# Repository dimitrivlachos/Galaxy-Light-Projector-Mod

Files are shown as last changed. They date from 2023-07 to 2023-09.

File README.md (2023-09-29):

# Galaxy Light Projector Mod
Modification of a consumer night-light projector, converting it into a smart device with a custom PCB, powered by an ESP-32.

## Features
- Alexa integration
- Complex color patterns
- Improved brightness
- Better circuit protection

## Custom PCB

### KiCad Render (Rev. 1.1)
<table>
  <tr>
    <td>Front</td>
  </tr>
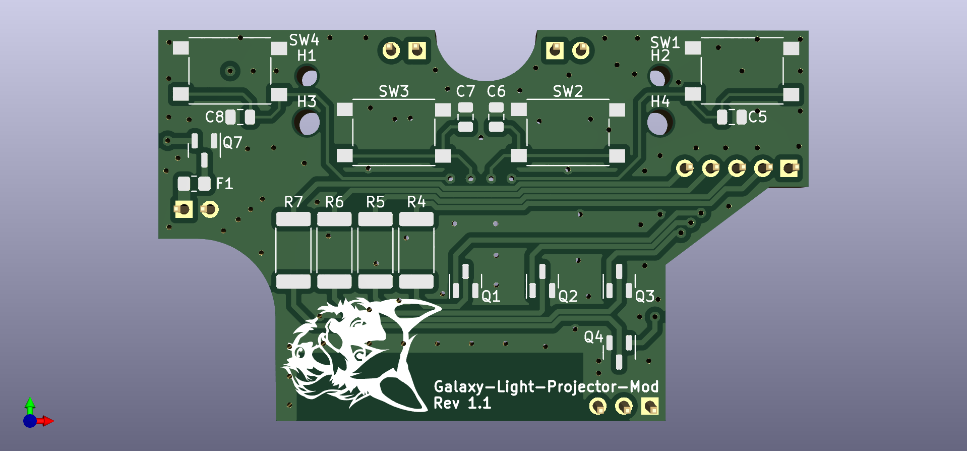
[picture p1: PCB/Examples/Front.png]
    <td></td>
  </tr>
  <tr>
    <td>Back</td>
  </tr>
  <tr>
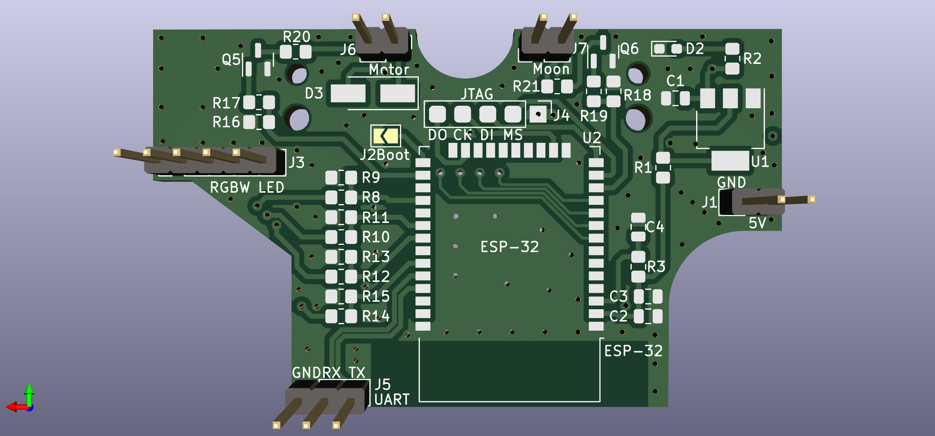
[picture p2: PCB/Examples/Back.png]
    <td></td>
 </table>

 ### Fabrication Render (Rev. 1.1)
  <table>
    <tr>
      <td>Front</td>
    </tr>
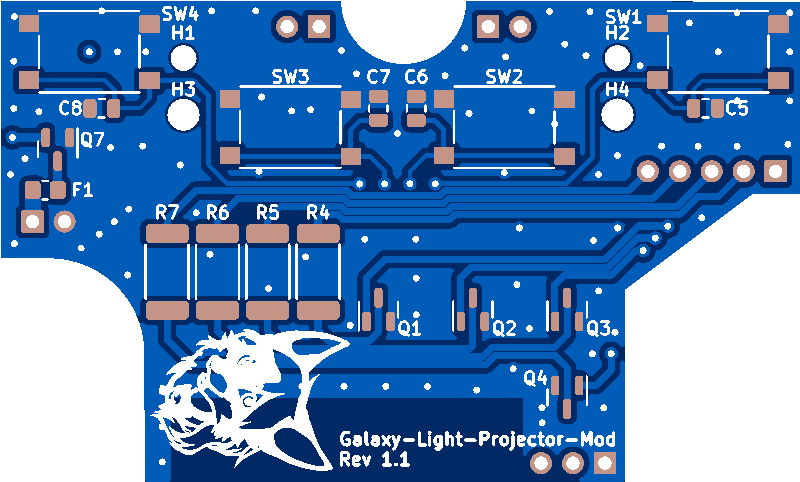
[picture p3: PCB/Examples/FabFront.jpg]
      <td></td>
    </tr>
    <tr>
      <td>Back</td>
    </tr>
    <tr>
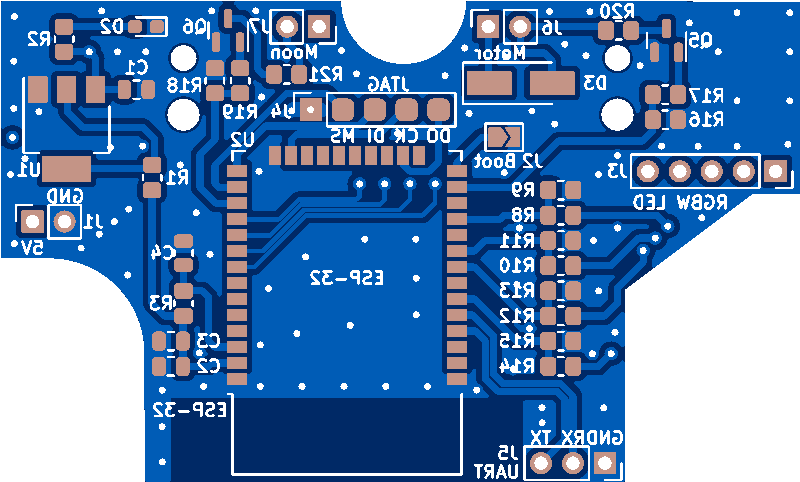
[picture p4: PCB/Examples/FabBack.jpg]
      <td></td>
    </table>

### Printed Circuit Board (Rev. 1.0)
<table>
  <tr>
    <td>Bare</td>
  </tr>
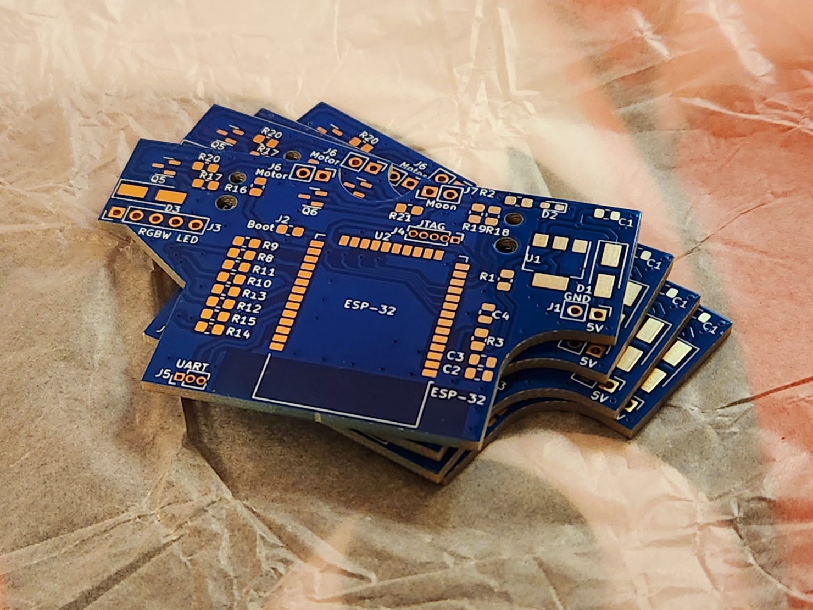
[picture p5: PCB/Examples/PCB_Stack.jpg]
    <td></td>
  <tr>
    <td>Assembled Front</td>
  </tr>
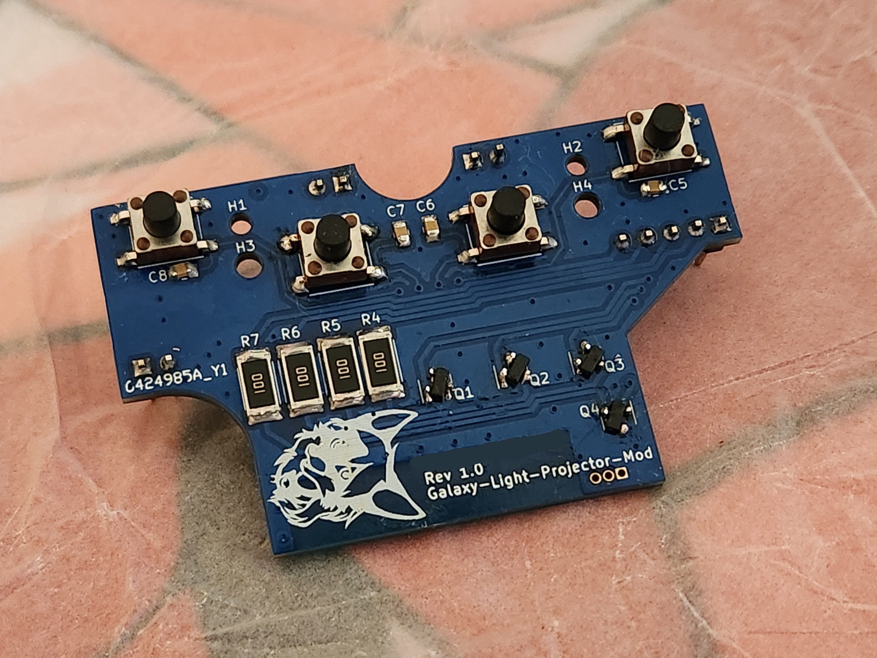
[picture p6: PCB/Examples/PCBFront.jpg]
    <td></td>
  </tr>
  <tr>
    <td>Assembled Back</td>
  </tr>
  <tr>
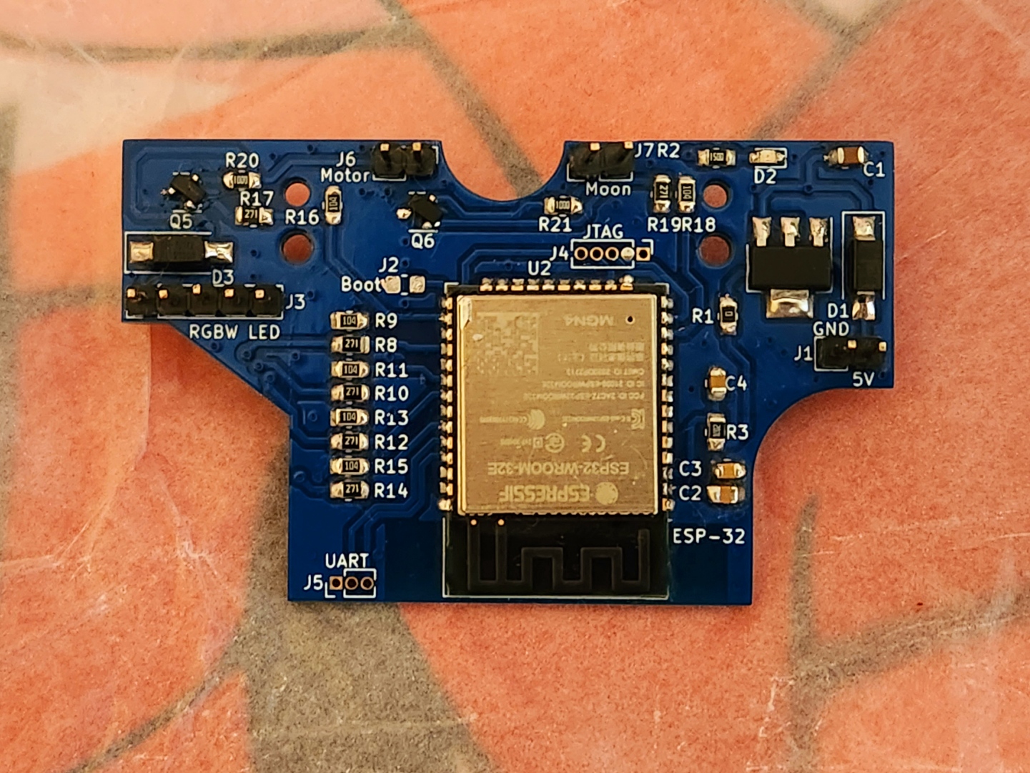
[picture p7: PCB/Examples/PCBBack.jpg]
    <td></td>
 </table>

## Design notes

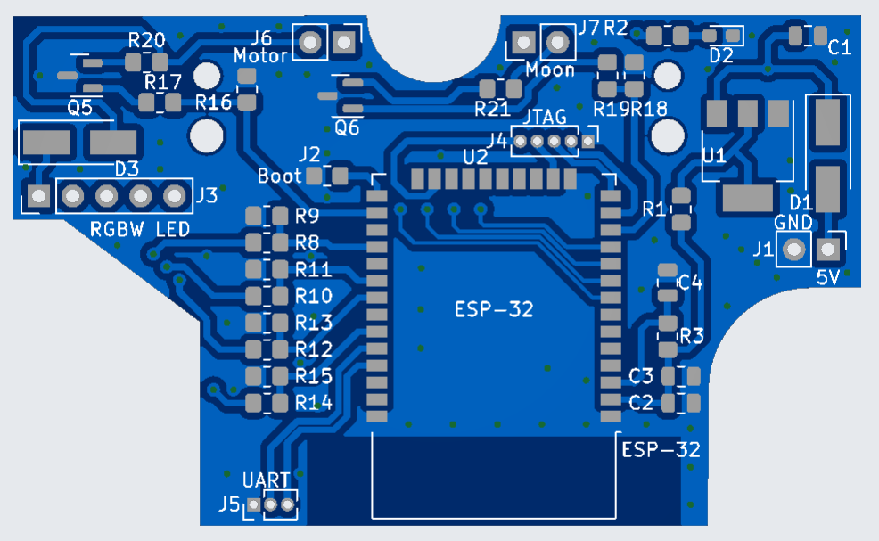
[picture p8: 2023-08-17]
PCB/Examples/FabBack.png

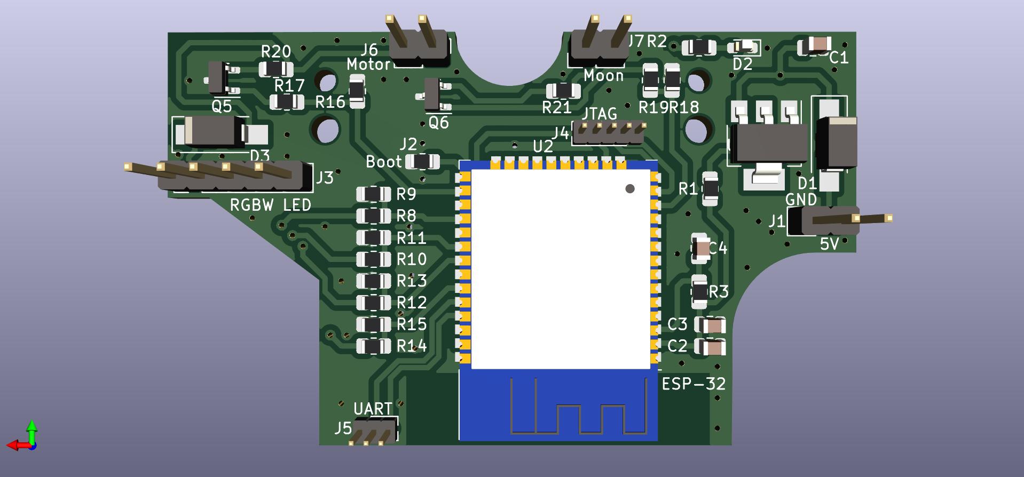
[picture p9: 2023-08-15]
PCB/Examples/Back.jpg

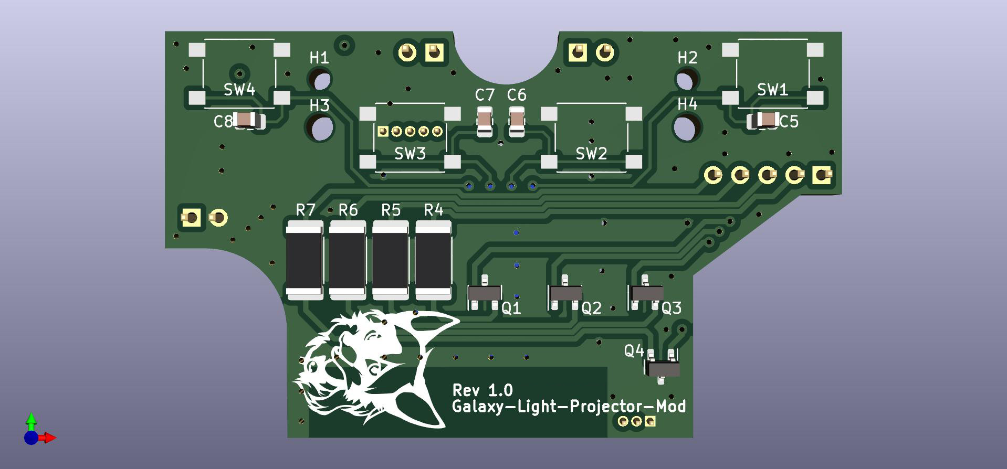
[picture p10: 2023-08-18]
PCB/Examples/Front.jpg

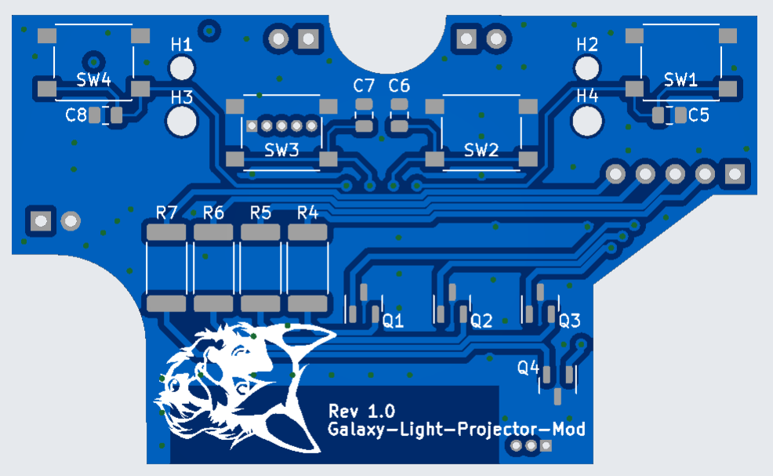
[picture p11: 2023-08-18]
PCB/Examples/FabFront.png

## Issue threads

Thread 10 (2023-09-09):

Switch footprint needs correction

dimitrivlachos, 2023-09-09:
Actual tactile switch footprint slightly different than described in datasheet and this needs correction on the board

Closed 2023-09-28.

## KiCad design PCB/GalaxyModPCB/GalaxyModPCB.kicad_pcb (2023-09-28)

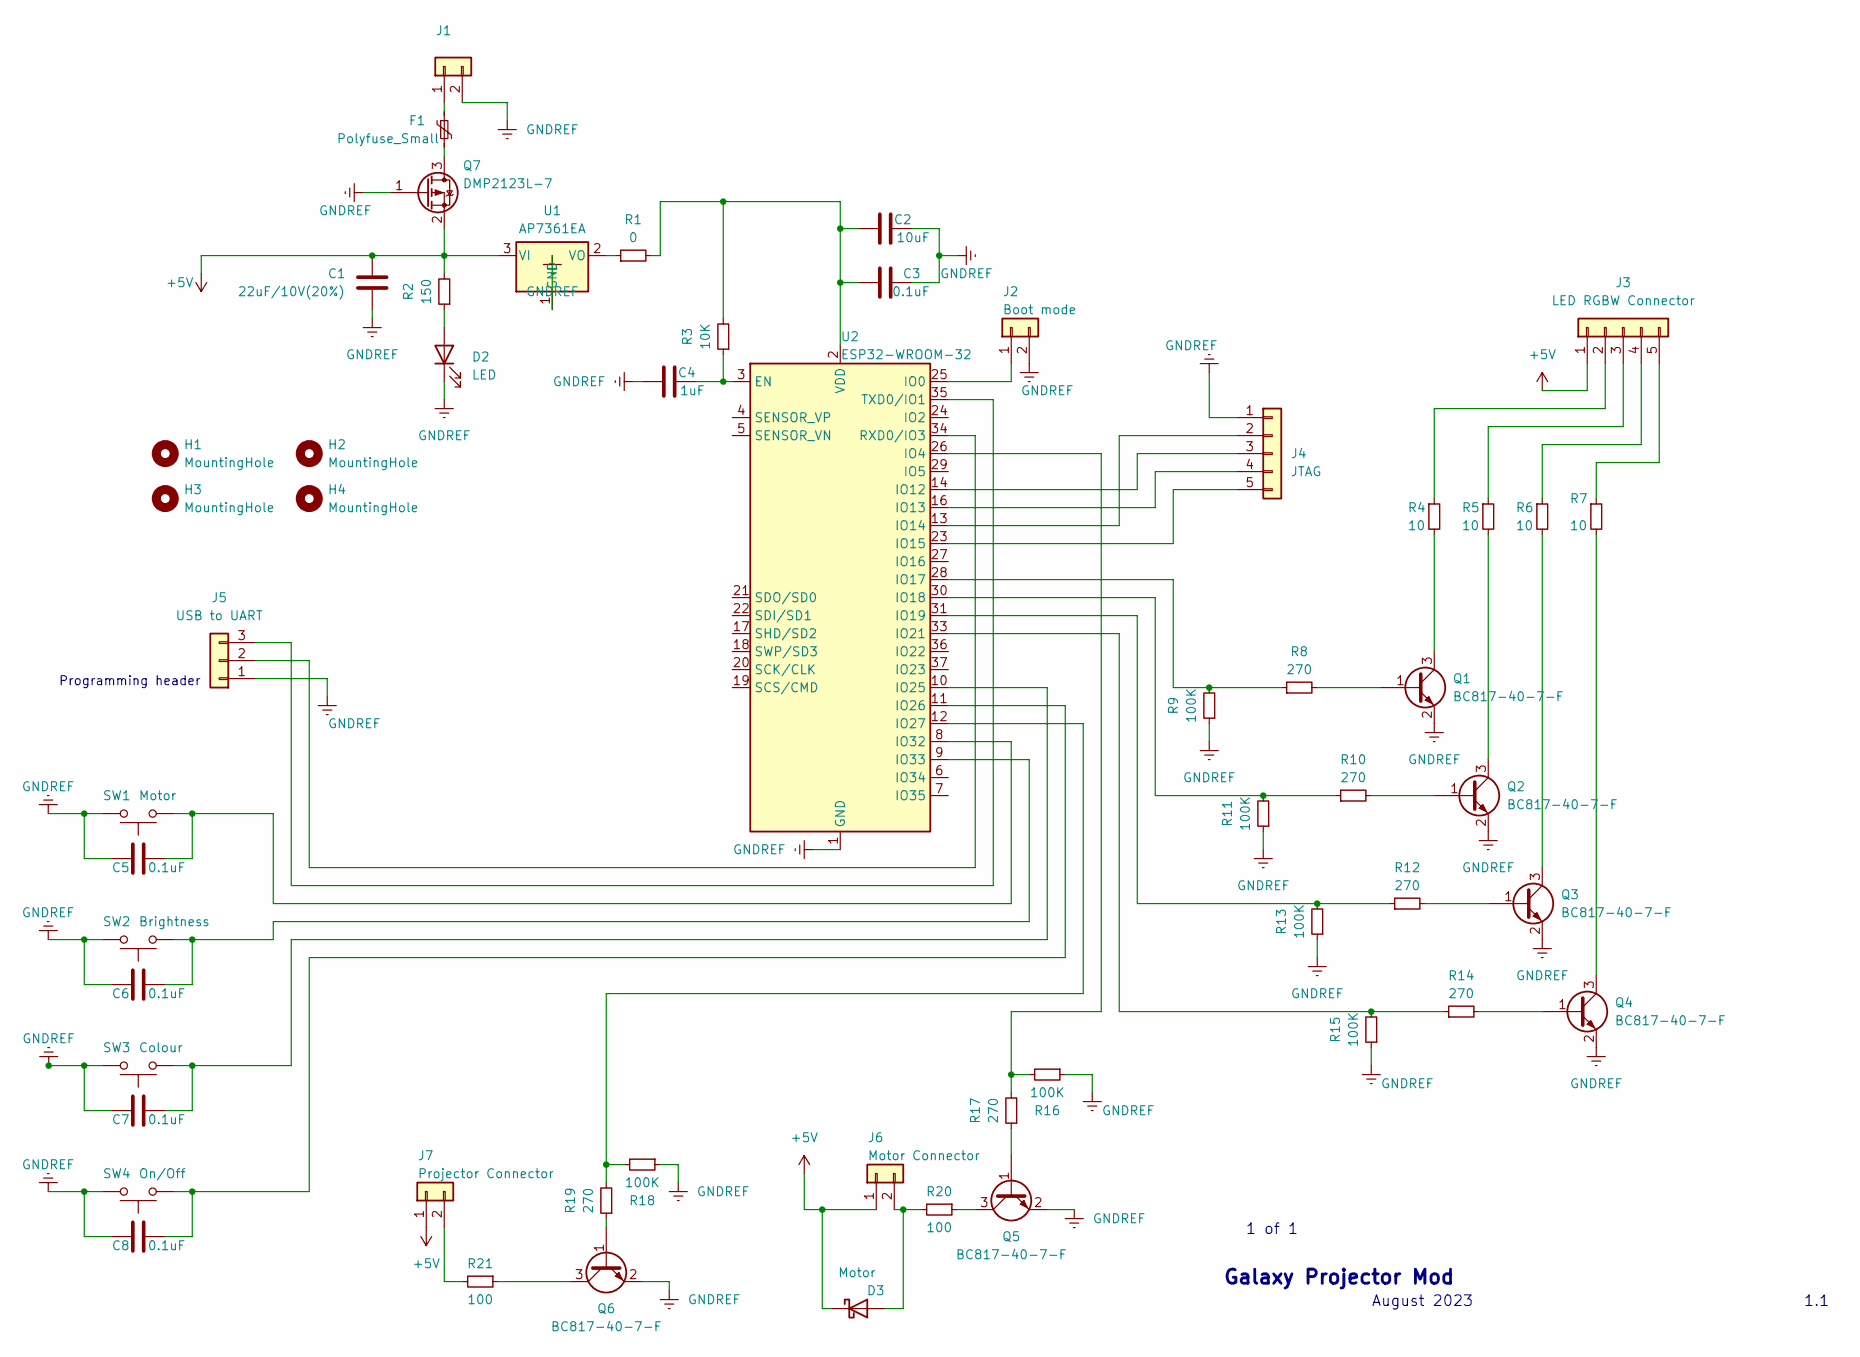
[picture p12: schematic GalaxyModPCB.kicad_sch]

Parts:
C1: 22uF/10V(20%); C_0805_2012Metric
C2: 10uF; C_0805_2012Metric
C3, C5, C6, C7, C8: 0.1uF; C_0805_2012Metric
C4: 1uF; C_0805_2012Metric
D2: LED; LED_0603_1608Metric_Pad1.05x0.95mm_HandSolder
D3: Motor; D_SMA_Handsoldering JLCPCB
F1: Polyfuse_Small; R_0805_2012Metric_Pad1.20x1.40mm_HandSolder
H1, H2: MountingHole; MountingHole_2mm Galaxy Small
H3, H4: MountingHole; 2.5mm Big Hole
J1: Power Header; PinHeader_1x02_P2.54mm_Vertical
J2: Boot mode; Triangle Jumper
J3: LED RGBW Connector; PinHeader_1x05_P2.54mm_Vertical
J4: JTAG; JTAG Connector
J5: USB to UART; UART Connector
J6: Motor Connector; PinHeader_1x02_P2.54mm_Vertical
J7: Projector Connector; PinHeader_1x02_P2.54mm_Vertical
Q1, Q2, Q3, Q4, Q5, Q6: BC817-40-7-F; SOT-23
Q7: DMP2123L-7; SOT-23
R1: 0; R_0805_2012Metric_Pad1.20x1.40mm_HandSolder
R2: 150; R_0805_2012Metric_Pad1.20x1.40mm_HandSolder
R3: 10K; R_0805_2012Metric_Pad1.20x1.40mm_HandSolder
R4, R5, R6, R7: 10; R_2512_6332Metric_Pad1.40x3.35mm_HandSolder
R8, R10, R12, R14, R17, R19: 270; R_0805_2012Metric_Pad1.20x1.40mm_HandSolder
R9, R11, R13, R15, R16, R18: 100K; R_0805_2012Metric_Pad1.20x1.40mm_HandSolder
R20, R21: 100; R_0805_2012Metric_Pad1.20x1.40mm_HandSolder
SW1: Motor; Galaxy Switch
SW2: Brightness; Galaxy Switch
SW3: Colour; Galaxy Switch
SW4: On/Off; Galaxy Switch
U1: AP7361EA; SOT-223-3_TabPin2
U2: ESP32-WROOM-32; ESP32-WROOM-32 No Thermal

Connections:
+5V: C1.1, D3.1 (K), J3.1, J6.1, J7.1, Q7.2 (S), R2.2, U1.3 (VI)
GNDREF: C1.2, C2.2, C3.2, C4.1, C5.2, C6.2, C7.2, C8.2, D2.1 (K), J1.2, J2.2, J4.1, J5.1, Q1.2 (E), Q2.2 (E), Q3.2 (E), Q4.2 (E), Q5.2 (E), Q6.2 (E), Q7.1 (G), R9.1, R11.1, R13.1, R15.1, R16.1, R18.1, SW1.2, SW2.2, SW3.2, SW4.2, U1.1 (GND), U2.1 (GND), U2.15 (GND), U2.38 (GND), U2.39 (GND)
unnamed: D2.2 (A), R2.1
unnamed: D3.2 (A), J6.2, R20.2
unnamed: F1.1, J1.1
unnamed: J2.1, U2.25 (IO0)
unnamed: J3.2, R4.1
unnamed: J3.3, R5.1
unnamed: J3.4, R6.1
unnamed: J3.5, R7.1
unnamed: J4.2, U2.13 (IO14)
unnamed: J4.3, U2.14 (IO12)
unnamed: J4.4, U2.16 (IO13)
unnamed: J4.5, U2.23 (IO15)
unnamed: J5.2, U2.34 (RXD0/IO3)
unnamed: J5.3, U2.35 (TXD0/IO1)
unnamed: J7.2, R21.2
unnamed: Q1.1 (B), R8.2
unnamed: Q1.3 (C), R4.2
unnamed: Q2.1 (B), R10.2
unnamed: Q2.3 (C), R5.2
unnamed: Q3.1 (B), R12.2
unnamed: Q3.3 (C), R6.2
unnamed: Q4.1 (B), R14.2
unnamed: Q4.3 (C), R7.2
unnamed: Q5.1 (B), R17.1
unnamed: Q5.3 (C), R20.1
unnamed: Q6.1 (B), R19.1
unnamed: Q6.3 (C), R21.1
unnamed: F1.2, Q7.3 (D)
unnamed: R1.1, U1.2 (VO)
unnamed: C4.2, R3.1, U2.3 (EN)
unnamed: R16.2, R17.2, U2.26 (IO4)
unnamed: R8.1, R9.2, U2.28 (IO17)
unnamed: R10.1, R11.2, U2.30 (IO18)
unnamed: R12.1, R13.2, U2.31 (IO19)
unnamed: R14.1, R15.2, U2.33 (IO21)
unnamed: C7.1, SW3.1, U2.10 (IO25)
unnamed: C8.1, SW4.1, U2.11 (IO26)
unnamed: R18.2, R19.2, U2.12 (IO27)
unnamed: C5.1, SW1.1, U2.8 (IO32)
unnamed: C6.1, SW2.1, U2.9 (IO33)
unnamed: C2.1, C3.1, R1.2, R3.2, U2.2 (VDD)

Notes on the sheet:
1.1
Galaxy Projector Mod
1 of 1
August 2023
Programming header

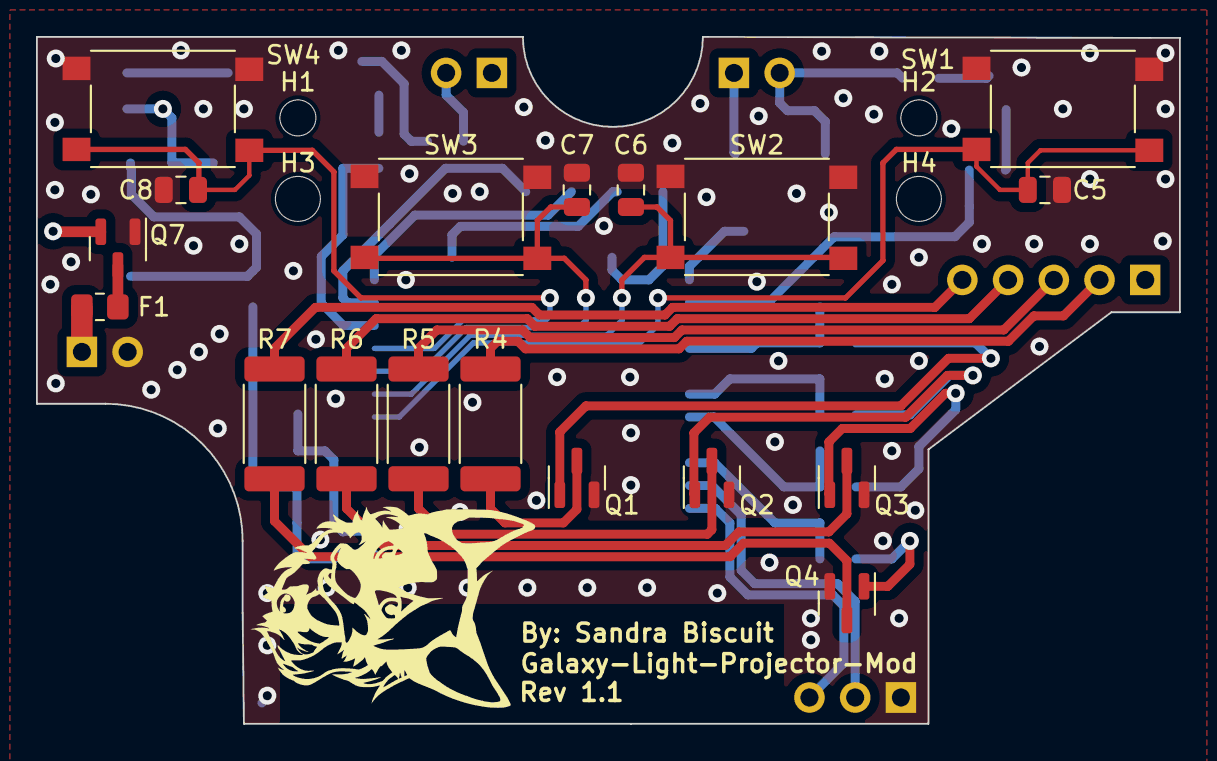
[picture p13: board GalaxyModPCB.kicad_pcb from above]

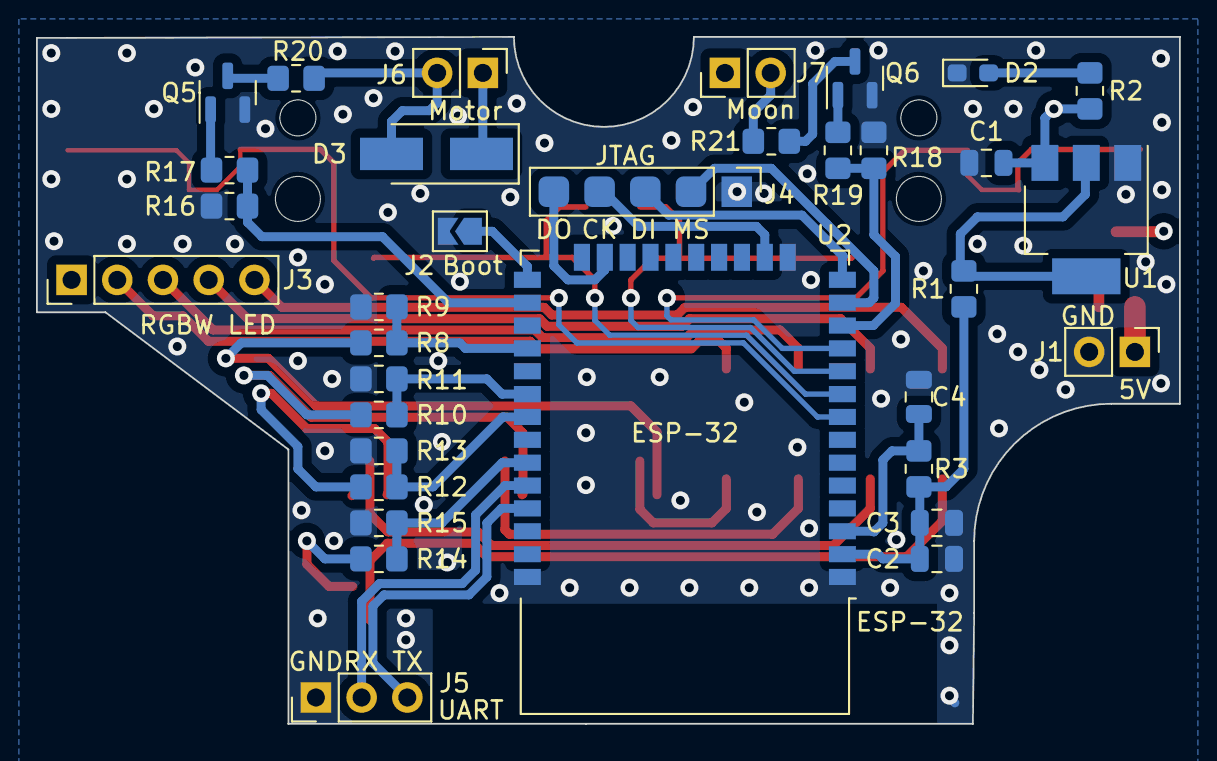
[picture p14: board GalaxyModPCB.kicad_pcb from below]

Board: 4 copper layers, 63.5 x 38.2 mm, 56 parts (34 on the bottom side), 43 nets.

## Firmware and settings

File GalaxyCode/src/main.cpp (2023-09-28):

#include <Arduino.h>
#include <WiFi.h>
#include <AsyncTCP.h>
#include <ESPAsyncWebServer.h>
#include <AsyncElegantOTA.h>
#include <Arduino_Json.h>

// Define and initialize the AsyncWebServer instance
AsyncWebServer server(80);
// Define and initialize the AsyncWebSocket instance
AsyncWebSocket ws("/ws");

// Task handles for the two core loops
TaskHandle_t TaskLoopCore0;
TaskHandle_t TaskLoopCore1;

// Switch state variables
bool motorSwitchState = false;
bool brightnessSwitchState = false;
bool colourSwitchState = false;
bool stateSwitchState = false;

// Brightness level variable
float brightness = 0.0;

// Maximum number of WiFi connection attempts
#define MAX_WIFI_ATTEMPTS 10
// Delay between WiFi connection attempts (in milliseconds)
#define WIFI_RETRY_DELAY 500
// Flag indicating WiFi connection status
bool wifiConnected = false;

#pragma region Function Declarations
// Core task function declarations
void LoopOutputHandle(void *pvParameters);
void LoopStateHandle(void *pvParameters);

// Function to connect to WiFi
void connectToWiFi();

// State handling function declarations
void setRGBWLed(int red, int green, int blue, int white);
void handlePowerState();
void handleRGBWState();
void handleMotorState();
void handleBrightnessState();

// Switch handling function declarations
void checkSwitch(int switchPin, bool &switchState, void (*callback)());
void handleStateSwitch();
void handleMotorSwitch();
void handleBrightnessSwitch();
void handleColourSwitch();

// Template function for incrementing enums
template <typename T>
T incrementEnum(T &enumValue, T lastEnumValue);

// Template function for handling switch state changes
template <typename EnumType>
void handleSwitch(EnumType &enumState, EnumType lastEnumValue, const char *switchName);

// WebSocket handling function declarations
void onEvent(AsyncWebSocket *server, AsyncWebSocketClient *client, AwsEventType type,
             void *arg, uint8_t *data, size_t len);
void handleWebSocketMessage(void *arg, uint8_t *payload, size_t length);
void initWebSocket();
String generateJsonForStates();
void updateClients();
#pragma endregion

#pragma region Wifi Settings
// WiFi configuration settings
const char *SSID = "ssid";
const char *PASSWORD = "pass";
const char *HOSTNAME = "GalaxyProjector-Dev";
const IPAddress STATIC_IP(192, 168, 0, 50);
const IPAddress GATEWAY(192, 168, 0, 1);
const IPAddress SUBNET(255, 255, 255, 0);
#pragma endregion

#pragma region Pin Definitions
// Pin definitions for various components
#define RED_LED 19            // Green wire
#define WHITE_LED 18          // Blue wire
#define GREEN_LED 17          // White wire
#define BLUE_LED 21           // Red wire
#define PROJECTOR_LED 27      // Moon projector
#define MOTOR_BJT 4           // Motor control
#define MOTOR_SWITCH 26       // Motor switch
#define BRIGHTNESS_SWITCH 25  // Brightness switch
#define COLOUR_SWITCH 33      // Colour switch
#define STATE_SWITCH 32       // State switch
#pragma endregion

#pragma region State Definitions
// Enumerations for various states
enum PowerStateEnum {
  PowerOff,
  On,
  Project,
  PowerLast
};
PowerStateEnum pStates = PowerOff;

enum RGBWStateEnum {
  Blue,
  Red,
  Green,
  White,
  BlueRed,
  BlueGreen,
  RedGreen,
  RedWhite,
  GreenWhite,
  RedGreenBlue,
  BlueGreenWhite,
  BlueRedGreenWhite,
  Cycle,
  LedLast
};
RGBWStateEnum rgbwStates = Blue;

enum MotorStateEnum {
  MotorOff,
  Fast,
  Slow,
  MotorLast
};
MotorStateEnum mStates = MotorOff;

enum BrightnessStateEnum {
  ExtraLow,
  Low,
  Medium,
  High,
  BrightnessLast
};
BrightnessStateEnum bStates = ExtraLow;
#pragma endregion

#pragma region HTML
const char index_html[] PROGMEM = R"rawliteral(
<!DOCTYPE HTML>
<html>
<head>
  <title>Galaxy Projector</title>
  <meta charset="UTF-8" name="viewport" content="width=device-width, initial-scale=1">
  <link rel="icon" href="data:,">
  <style>
    html {
      font-family: 'Arial', sans-serif;
      text-align: center;
      background-color: #111111;
      color: #ffffff;
    }
    h1 {
      font-size: 2rem;
      margin: 1rem;
    }
    h2 {
      font-size: 1.8rem;
      font-weight: bold;
      color: #00bfff;
    }
    .topnav {
      overflow: hidden;
      background-color: #111111;
      padding: 1rem;
    }
    body {
      margin: 0;
    }
    .content {
      padding: 2rem;
      max-width: 800px;
      margin: 0 auto;
    }
    .card {
      background-color: #1a1a1a;
      box-shadow: 0 0 10px rgba(255, 255, 255, 0.2);
      padding: 1rem;
      border-radius: 10px;
      text-align: center;
    }
    .button {
      padding: 15px 50px;
      font-size: 24px;
      text-align: center;
      outline: none;
      color: #fff;
      background-color: #00bfff;
      border: none;
      border-radius: 5px;
      cursor: pointer;
    }
    .button:active {
      background-color: #0099cc;
      box-shadow: 2px 2px 5px rgba(0, 0, 0, 0.3);
      transform: translateY(2px);
    }
    .state {
      font-size: 1.2rem;
      color: #8c8c8c;
    }
    .grid-container {
      display: grid;
      grid-template-columns: repeat(auto-fit, minmax(250px, 1fr));
      gap: 20px;
      margin-top: 1rem;
    }
  </style>
</head>
<body>
  <div class="topnav">
    <h1>🌠 Galaxy Projector 🌌</h1>
  </div>
  <div class="content">
    <div class="grid-container">
      <div class="card">
        <h2>Power</h2>
        <p><button id="Power" class="button">⚡️</button></p>
        <p class="state" id="PowerState">State: </p>
      </div>
      <div class="card">
        <h2>Brightness</h2>
        <p><button id="Brightness" class="button">☀️</button></p>
        <p class="state" id="BrightnessState">State: </p>
      </div>
      <div class="card">
        <h2>Colour</h2>
        <p><button id="Colour" class="button">🌈</button></p>
        <p class="state" id="ColourState">State: </p>
      </div>
      <div class="card">
        <h2>Spin</h2>
        <p><button id="Motor" class="button">💫</button></p>
        <p class="state" id="MotorState">State: </p>
      </div>
      <!-- Add more cards here -->
    </div>
  </div>
    <script>
      var gateway = `ws://${window.location.hostname}/ws`;
      var websocket;
      var statesDict = {
        "Power": ['🌑', '🌓', '🌕'],
        "Brightness": ['🌒', '🌓', '🌔', '🌕'],
        "Colour": ['🔵', '🔴', '🟢', '⚪️', '🔵🔴', '🔵🟢', '🔴🟢', '🔴⚪️', '🟢⚪️', '🔴🟢🔵', '🔵🟢⚪️', '🔵🔴🟢⚪️', '🔄'],
        "Motor": ['🛑', '🐇', '🐢']
      };
      window.addEventListener('load', onLoad);
  
      function initWebSocket() {
        console.log('Trying to open a WebSocket connection...');
        websocket = new WebSocket(gateway);
        websocket.onopen    = onOpen;
        websocket.onclose   = onClose;
        websocket.onmessage = onMessage;
      }
  
      function onOpen(event) {
        console.log('Connection opened');
        // Update the state of the buttons with the data received from the server
        sendMessage('getStates');
      }
  
      function onClose(event) {
        console.log('Connection closed');
        setTimeout(initWebSocket, 2000);
      }
  
      function onMessage(event) {
        console.log(`Received a message from server: ${event.data}`);
        try {
          var jsonData = JSON.parse(event.data);
          updateStates(jsonData);
        } catch (error) {
          console.error('Error parsing JSON:', error);
        }
      }
  
      function updateStates(data) {
        for (var key in data) {
          var stateElement = document.getElementById(key + 'State');
          if (stateElement) {
            stateElement.textContent = 'State: ' + statesDict[key][data[key]];
          }
        }
      }
  
      function onLoad(event) {
        initWebSocket();
        initButtons();
      }
  
      function initButtons() {
        // Initialize the buttons with their respective ids and listeners
        addButtonListener("Power");
        addButtonListener("Brightness");
        addButtonListener("Colour");
        addButtonListener("Motor");
      }
  
      function addButtonListener(buttonId) {
        var button = document.getElementById(buttonId);
        button.addEventListener('click', function() {
          sendMessage(buttonId);
        });
        button.buttonId = buttonId; // Store the button's id as a property for later use
      }
  
      function sendMessage(buttonId) {
        websocket.send(buttonId); // Send the button's id as a message to the ESP
      }
    </script>
</body>
</html>
)rawliteral";
#pragma endregion

void setup() {
  Serial.begin(115200);
  Serial.println("Booting");

  #pragma region Pin Initialisation
  pinMode(RED_LED, OUTPUT);
  pinMode(WHITE_LED, OUTPUT);
  pinMode(GREEN_LED, OUTPUT);
  pinMode(BLUE_LED, OUTPUT);
  pinMode(PROJECTOR_LED, OUTPUT);
  pinMode(MOTOR_BJT, OUTPUT);
  
  // Switches are active low so use INPUT_PULLUP
  pinMode(MOTOR_SWITCH, INPUT_PULLUP);
  pinMode(BRIGHTNESS_SWITCH, INPUT_PULLUP);
  pinMode(COLOUR_SWITCH, INPUT_PULLUP);
  pinMode(STATE_SWITCH, INPUT_PULLUP);
  #pragma endregion

  connectToWiFi();

  if(wifiConnected) {
    // Initialise WebSocket
    Serial.println("Initialising WebSocket");
    initWebSocket();
    Serial.println("WebSocket initialised");

    // Initialise OTA
    Serial.println("Initialising OTA");
    server.on("/", HTTP_GET, [](AsyncWebServerRequest *request) {
      request->send_P(200, "text/html", index_html);
    });
    AsyncElegantOTA.begin(&server);    // Start AsyncElegantOTA
    server.begin();
    Serial.println("HTTP server started");
    Serial.println("OTA initialised");
  }
  else {
    Serial.println("WiFi not connected, OTA not initialised. WebSocket not initialised. Continuing offline...");
  }

  Serial.println("Initialising Tasks");
  
  Serial.print("Initialising TaskLoopCore1... ");
  xTaskCreatePinnedToCore(
    LoopOutputHandle,     /* Task function. */
    "TaskLoopCore1",      /* name of task. */
    10000,                /* Stack size of task */
    NULL,                 /* parameter of the task */
    1,                    /* priority of the task */
    &TaskLoopCore0,       /* Task handle to keep track of created task */
    1);                   /* pin task to core 1 */          
  delay(500); 

  Serial.print("Initialising TaskLoopCore0... ");
  xTaskCreatePinnedToCore(
    LoopStateHandle,      /* Task function. */
    "TaskLoopCore0",      /* name of task. */
    10000,                /* Stack size of task */
    NULL,                 /* parameter of the task */
    1,                    /* priority of the task */
    &TaskLoopCore1,       /* Task handle to keep track of created task */
    0);                   /* pin task to core 0 */
  delay(500); 

  Serial.println("Tasks initialised");
  Serial.println("Setup complete!");
}

/**
 * Connects the device to a WiFi network using the provided SSID and password.
 * 
 * This function configures the WiFi mode, begins the connection process, sets the hostname,
 * and configures the IP address (if STATIC_IP is defined). It then attempts to connect
 * to the WiFi network, displaying connection progress. If the connection is successful,
 * the function updates the wifiConnected variable to true and prints the device's IP address.
 * If the connection fails, the function prints an error message, disconnects from WiFi,
 * and sets wifiConnected to false, allowing the device to continue offline.
 */
void connectToWiFi() {
  Serial.println("Connecting to WiFi...");
  
  // Set WiFi mode and begin connection
  WiFi.mode(WIFI_STA);
  WiFi.begin(SSID, PASSWORD);
  WiFi.setHostname(HOSTNAME);
  WiFi.config(STATIC_IP, GATEWAY, SUBNET);

  // Attempt to connect to WiFi
  int attemptCount = 0;
  while (WiFi.status() != WL_CONNECTED && attemptCount < MAX_WIFI_ATTEMPTS) {
    delay(WIFI_RETRY_DELAY);
    Serial.print(".");
    attemptCount++;
  }

  if (WiFi.status() == WL_CONNECTED) {
    Serial.println("\nConnected to WiFi");
    Serial.print("IP address: ");
    Serial.println(WiFi.localIP());
    wifiConnected = true; // Update wifiConnected status
  } else {
    Serial.println("\nFailed to connect to WiFi");
    WiFi.disconnect();    // Disconnect from WiFi
    wifiConnected = false; // Update wifiConnected status
    // Continue offline
    return;
  }
}

void loop() {
  ws.cleanupClients(); // Cleanup disconnected clients
}

#pragma region Output Handlers
/**
 * Task function to handle the output loop on a specific core.
 *
 * This task function is responsible for managing the output-related operations
 * of the device. It continuously handles the power state, brightness state,
 * RGBW state, and motor state according to their respective conditions.
 *
 * @param pvParameters A pointer to the parameters passed to the task (not used in this case).
 */
void LoopOutputHandle(void *pvParameters) {
  // Print the core ID for debugging purposes
  Serial.print("TaskLoopCore1 running on core ");
  Serial.println(xPortGetCoreID());

  // Enter the main loop
  for (;;) {
    // Handle power state regardless of other states
    handlePowerState();

    // Skip handling other states if the device is powered off
    if (pStates == PowerStateEnum::PowerOff) {
      continue;
    }

    // Handle brightness state
    handleBrightnessState();

    // Handle RGBW state
    handleRGBWState();

    // Handle motor state
    handleMotorState();
  }
}

/**
 * Handle power state and associated actions.
 *
 * This function is responsible for handling the power state of the device and
 * performing relevant actions based on the current power state. It controls the
 * LED colors, projector state, and motor state according to the power state.
 * If the power state is not recognized, an error message is printed to the serial monitor.
 *
 * @remarks The function behaviors in different power states:
 *   - PowerOff: Turns off all LEDs, deactivates the projector and motor.
 *   - On: Allows other state handlers to be executed, facilitating state transitions.
 *   - Project: Activates the projector and allows other state handlers to be executed.
 *     The projector LED will be on in this state.
 */
void handlePowerState() {
  switch (pStates) {
    case PowerStateEnum::PowerOff:
      // Turn off all LEDs and deactivate the projector and motor
      analogWrite(RED_LED, 0);
      analogWrite(GREEN_LED, 0);
      analogWrite(BLUE_LED, 0);
      analogWrite(WHITE_LED, 0);
      digitalWrite(PROJECTOR_LED, LOW);
      analogWrite(MOTOR_BJT, 0);
      break;
    case PowerStateEnum::On:
      // Being in this state allows the other states to be handled
      // Otherwise, the other state handlers will be skipped
      break;
    case PowerStateEnum::Project:
      // Activate the projector
      digitalWrite(PROJECTOR_LED, HIGH);
      // Being in this state allows the other states to be handled
      // Otherwise, the other state handlers will be skipped
      // In this case, the projector LED will be on as well.
      break;
    default:
      // Print an error message for unrecognized power state
      Serial.println("Invalid Power State");
      break;
  }
}

/**
 * Handle brightness state and set the global brightness level modifier.
 *
 * This function is responsible for adjusting the global brightness level modifier of the
 * device's LED colors based on the current brightness state. The brightness level
 * is controlled by modifying the 'brightness' variable. If the brightness state is
 * not recognized, an error message is printed to the serial monitor.
 *
 * @remarks The function behaviors in different brightness states:
 *   - ExtraLow: Sets the brightness to 25% of the maximum level.
 *   - Low: Sets the brightness to 50% of the maximum level.
 *   - Medium: Sets the brightness to 75% of the maximum level.
 *   - High: Sets the brightness to the maximum level (100%).
 */
void handleBrightnessState() {
  switch (bStates) {
    case BrightnessStateEnum::ExtraLow:
      // Set the brightness to 25% of the maximum level
      brightness = 0.25;
      break;
    case BrightnessStateEnum::Low:
      // Set the brightness to 50% of the maximum level
      brightness = 0.5;
      break;
    case BrightnessStateEnum::Medium:
      // Set the brightness to 75% of the maximum level
      brightness = 0.75;
      break;
    case BrightnessStateEnum::High:
      // Set the brightness to the maximum level (100%)
      brightness = 1;
      break;
    default:
      // Print an error message for unrecognized brightness state
      Serial.println("Invalid Brightness State");
      break;
  }
}

/**
 * Handle RGBW state and set the RGBW LED colors based on the current state.
 *
 * This function is responsible for setting the RGBW LED colors based on the current
 * RGBW state. The RGBW LED colors are determined by the 'rgbwStates' variable.
 * If the RGBW state is not recognized, an error message is printed to the serial monitor.
 */
void handleRGBWState() {
  switch(rgbwStates) {
    case RGBWStateEnum::Blue:
      setRGBWLed(0, 0, 255, 0);
      break;
    case RGBWStateEnum::Red:
      setRGBWLed(255, 0, 0, 0);
      break;
    case RGBWStateEnum::Green:
      setRGBWLed(0, 255, 0, 0);
      break;
    case RGBWStateEnum::White:
      setRGBWLed(0, 0, 0, 255);
      break;
    case RGBWStateEnum::BlueRed:
      setRGBWLed(255, 0, 255, 0);
      break;
    case RGBWStateEnum::BlueGreen:
      setRGBWLed(0, 255, 255, 0);
      break;
    case RGBWStateEnum::RedGreen:
      setRGBWLed(255, 255, 0, 0);
      break;
    case RGBWStateEnum::RedWhite:
      setRGBWLed(255, 0, 0, 255);
      break;
    case RGBWStateEnum::GreenWhite:
      setRGBWLed(0, 255, 0, 255);
      break;
    case RGBWStateEnum::RedGreenBlue:
      setRGBWLed(255, 255, 255, 0);
      break;
    case RGBWStateEnum::BlueGreenWhite:
      setRGBWLed(0, 255, 255, 255);
      break;
    case RGBWStateEnum::BlueRedGreenWhite:
      setRGBWLed(255, 255, 255, 255);
      break;
    case RGBWStateEnum::Cycle:
      // Cycle through the colours using a sine wave on millis()
      setRGBWLed(
        127.5 * (1 + sin(millis() / 1000.0)),               // Red
        127.5 * (1 + sin(millis() / 1000.0 + 2 * PI / 3)),  // Green
        127.5 * (1 + sin(millis() / 1000.0 + 4 * PI / 3)),  // Blue
        0);                                                 // White
      break;
    default:
      Serial.println("Invalid RGBW State");
      break;
  }
}

/**
 * Handle motor state and control the motor speed based on the current state.
 *
 * This function is responsible for controlling the motor speed based on the current
 * motor state. The motor speed is controlled by adjusting the analog output value
 * to the MOTOR_BJT pin. If the motor state is not recognized, an error message is
 * printed to the serial monitor.
 *
 * @remarks The function behaviors in different motor states:
 *   - MotorOff: Turns off the motor by setting analog output to 0.
 *   - Fast: Sets the motor speed to maximum (255) using analog output.
 *   - Slow: Sets the motor speed to a moderate value (200) using analog output.
 */
void handleMotorState() {
  switch (mStates) {
    case MotorStateEnum::MotorOff:
      // Turn off the motor by setting analog output to 0
      analogWrite(MOTOR_BJT, 0);
      break;
    case MotorStateEnum::Fast:
      // Set the motor speed to maximum (255) using analog output
      analogWrite(MOTOR_BJT, 255);
      break;
    case MotorStateEnum::Slow:
      // Set the motor speed to a moderate value (200) using analog output
      analogWrite(MOTOR_BJT, 200);
      break;
    default:
      // Print an error message for unrecognized motor state
      Serial.println("Invalid Motor State");
      break;
  }
}

/**
 * Set the RGBW LED color and adjust brightness.
 *
 * This function sets the color of the RGBW LED by adjusting the analog output values
 * for each color channel (red, green, blue, white) based on the specified values
 * and the current brightness level. The brightness factor is multiplied with the
 * input color values to control the overall brightness of the LED.
 *
 * @param red The intensity of the red color channel (0-255).
 * @param green The intensity of the green color channel (0-255).
 * @param blue The intensity of the blue color channel (0-255).
 * @param white The intensity of the white color channel (0-255).
 */
void setRGBWLed(int red, int green, int blue, int white) {
  // Adjust the color intensity using the current brightness level
  analogWrite(RED_LED, red * brightness);
  analogWrite(GREEN_LED, green * brightness);
  analogWrite(BLUE_LED, blue * brightness);
  analogWrite(WHITE_LED, white * brightness);
}
#pragma endregion

#pragma region State Handlers
/**
 * Task function for monitoring and handling switch states.
 *
 * This task function is responsible for continuously monitoring the states of various switches
 * and invoking their corresponding handler functions when the switches are pressed or released.
 * The function includes a delay to prevent excessive CPU usage within the loop.
 *
 * @param pvParameters Pointer to task parameters (not used in this case).
 */
void LoopStateHandle( void * pvParameters ){
  Serial.print("TaskLoopCore1 running on core ");
  Serial.println(xPortGetCoreID());

  for(;;){
    // Check the states of various switches and invoke their handlers
    checkSwitch(MOTOR_SWITCH, motorSwitchState, handleMotorSwitch);
    checkSwitch(BRIGHTNESS_SWITCH, brightnessSwitchState, handleBrightnessSwitch);
    checkSwitch(COLOUR_SWITCH, colourSwitchState, handleColourSwitch);
    checkSwitch(STATE_SWITCH, stateSwitchState, handleStateSwitch);
    
    // Delay for 10ms to prevent the task from hogging the CPU
    vTaskDelay(10 / portTICK_PERIOD_MS);
  }
}
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

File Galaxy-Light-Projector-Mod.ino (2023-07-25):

#include <ESP8266WiFi.h>
#include <ESP8266mDNS.h>
#include <WiFiUdp.h>
#include <ArduinoOTA.h>

#ifndef STASSID
#define STASSID "your-ssid"
#define STAPSK "your-password"
#endif

const char* ssid = STASSID;
const char* password = STAPSK;

// Define the pin that the LED is connected to
#define LED_PIN D4

// Define the delay between blinks
#define BLINK_DELAY_MS 1000

// Setup function runs once when the board is powered on or reset
void setup() {
  #pragma region OTA Setup
  // OTA Initialization
  Serial.begin(115200);
  Serial.println("Booting");
  WiFi.mode(WIFI_STA);
  WiFi.begin(ssid, password);
  while (WiFi.waitForConnectResult() != WL_CONNECTED) {
    Serial.println("Connection Failed! Rebooting...");
    delay(5000);
    ESP.restart();
  }
  // Once wifi connected, define
  ArduinoOTA.setHostname("Galaxy Night Light");

  ArduinoOTA.onStart([]() {
    String type;
    if (ArduinoOTA.getCommand() == U_FLASH) {
      type = "sketch";
    } else {  // U_FS
      type = "filesystem";
    }

    // NOTE: if updating FS this would be the place to unmount FS using FS.end()
    Serial.println("Start updating " + type);
  });
  ArduinoOTA.onEnd([]() {
    Serial.println("\nEnd");
  });
  ArduinoOTA.onProgress([](unsigned int progress, unsigned int total) {
    Serial.printf("Progress: %u%%\r", (progress / (total / 100)));
  });
  ArduinoOTA.onError([](ota_error_t error) {
    Serial.printf("Error[%u]: ", error);
    if (error == OTA_AUTH_ERROR) {
      Serial.println("Auth Failed");
    } else if (error == OTA_BEGIN_ERROR) {
      Serial.println("Begin Failed");
    } else if (error == OTA_CONNECT_ERROR) {
      Serial.println("Connect Failed");
    } else if (error == OTA_RECEIVE_ERROR) {
      Serial.println("Receive Failed");
    } else if (error == OTA_END_ERROR) {
      Serial.println("End Failed");
    }
  });
  ArduinoOTA.begin();
  Serial.println("Ready");
  Serial.print("IP address: ");
  Serial.println(WiFi.localIP());
  #pragma endregion
  
  // Initialize the LED pin as an output
  pinMode(LED_PIN, OUTPUT);
}

// Loop function runs over and over again forever
void loop() {
  // Handle OTA functions
  ArduinoOTA.handle();

  // Turn the LED on
  digitalWrite(LED_PIN, HIGH);

  // Wait for the specified delay
  delay(BLINK_DELAY_MS);

  // Turn the LED off
  digitalWrite(LED_PIN, LOW);

  // Wait for the specified delay
  delay(BLINK_DELAY_MS);
}

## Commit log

2023-07-31 Created empty PCB sketch
    Created a KiCad project for the design of the PCB for this project
    [GalaxyModPCB.kicad_pcb, GalaxyModPCB.kicad_sch]
2023-08-01 Began work on basic schematic
    [GalaxyModPCB.kicad_sch]
2023-08-01 Placed correct ESP board
    [GalaxyModPCB.kicad_sch]
2023-08-01 Added voltage regulator circuitry
    [GalaxyModPCB.kicad_sch]
2023-08-01 Changed to esp32
    [GalaxyModPCB.kicad_sch]
2023-08-01 Neatened wiring
    [GalaxyModPCB.kicad_sch]
2023-08-01 Changed to connector
    [GalaxyModPCB.kicad_sch]
2023-08-02 First draft drawn
    [GalaxyModPCB.kicad_sch]
2023-08-02 Labelled and named
    [GalaxyModPCB.kicad_sch]
2023-08-02 Added switches
    [GalaxyModPCB.kicad_sch]
2023-08-02 Added debugging header
    [GalaxyModPCB.kicad_sch]
2023-08-02 Fixed annotations
    [GalaxyModPCB.kicad_sch]
2023-08-02 Fixed connector footprints
    [GalaxyModPCB.kicad_sch]
2023-08-02 Added power connector
    [GalaxyModPCB.kicad_sch]
2023-08-02 Assigned footprints
    [GalaxyModPCB.kicad_sch]
2023-08-02 Laid out basic PCB arrangement
    [GalaxyModPCB.kicad_pcb]
2023-08-03 Copied original PCB edge cuts
    [GalaxyModPCB.kicad_pcb]
2023-08-03 Added boot mode header
    [GalaxyModPCB.kicad_sch]
2023-08-03 Fixed pin header footprints
    [GalaxyModPCB.kicad_sch]
2023-08-03 Updated footprints on PCB
    [GalaxyModPCB.kicad_pcb]
2023-08-03 Updated switch footprints
    [GalaxyModPCB.kicad_pcb]
2023-08-03 Adjusted board
    [GalaxyModPCB.kicad_pcb]
2023-08-03 Aligned switches
    [GalaxyModPCB.kicad_pcb]
2023-08-03 Added board cutout
    [GalaxyModPCB.kicad_pcb]
2023-08-03 Fixed power header size
    [GalaxyModPCB.kicad_pcb, GalaxyModPCB.kicad_sch]
2023-08-03 Fixed RVP diode
    [GalaxyModPCB.kicad_sch]
2023-08-03 Arranged power supply
    [GalaxyModPCB.kicad_pcb]
2023-08-03 Wired power circuitry
    [GalaxyModPCB.kicad_pcb]
2023-08-03 Fixed small tracing issue
    [GalaxyModPCB.kicad_pcb]
2023-08-03 Fixed traces
    [GalaxyModPCB.kicad_pcb]
2023-08-03 Connect switch peripherals
    [GalaxyModPCB.kicad_pcb]
2023-08-03 Fixed motor diode footprint
    [GalaxyModPCB.kicad_pcb, GalaxyModPCB.kicad_sch]
2023-08-03 Fixed sketch trace connections
    [GalaxyModPCB.kicad_pcb, GalaxyModPCB.kicad_sch]
2023-08-03 Fixed RVP of sketch
    [GalaxyModPCB.kicad_pcb, GalaxyModPCB.kicad_sch]
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2023-08-03 Added cutout for antenna
    [GalaxyModPCB.kicad_pcb]
2023-08-03 Connected power to esp32
    [GalaxyModPCB.kicad_pcb]
2023-08-03 Fixed SW1 connection
    [GalaxyModPCB.kicad_pcb, GalaxyModPCB.kicad_sch]
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2023-08-03 Wired up LED header
    [GalaxyModPCB.kicad_pcb]
2023-08-03 Began work on projector LED
    [GalaxyModPCB.kicad_pcb]
2023-08-03 Corrected projector LED power
    [GalaxyModPCB.kicad_sch]
2023-08-03 Updated projector LED requirements
    [GalaxyModPCB.kicad_pcb]
2023-08-03 Corrected component sides
    [GalaxyModPCB.kicad_pcb]
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2023-08-03 Updated LED resistors
    Changed from 4 small to 1 large resistor per LED. This doubles the heat dissipation and reduces footprint
    [GalaxyModPCB.kicad_pcb, GalaxyModPCB.kicad_sch]
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2023-08-03 Connected all but ground
    [GalaxyModPCB.kicad_pcb]
2023-08-04 Added mounting holes to sketch
    [GalaxyModPCB.kicad_pcb, GalaxyModPCB.kicad_sch]
2023-08-04 Fixed mounting holes
    [GalaxyModPCB.kicad_pcb, GalaxyModPCB.kicad_sch]
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2023-08-04 Accounted for mounting holes
    [GalaxyModPCB.kicad_pcb]
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2023-08-04 Added JLCPCB custom rules
    [GalaxyModPCB.kicad_pcb]
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2023-08-04 Changed headers to pins
    [GalaxyModPCB.kicad_pcb]
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2023-08-05 Part separation for reconfiguration
    [GalaxyModPCB.kicad_pcb, GalaxyModPCB.kicad_sch]
2023-08-05 Fixed transistor direction
    [GalaxyModPCB.kicad_sch]
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2023-08-05 Updated 0 ohm resistor
    [GalaxyModPCB.kicad_pcb]
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2023-08-05 Arranged and connected power
    [GalaxyModPCB.kicad_pcb]
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2023-08-05 Roughly placed most components
    [GalaxyModPCB.kicad_pcb]
2023-08-06 Arranged parts for tracing
    [GalaxyModPCB.kicad_pcb]
2023-08-06 Initial power traces drawn
    [GalaxyModPCB.kicad_pcb]
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2023-08-08 Fixed multiple vias
    [GalaxyModPCB.kicad_pcb]
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2023-08-08 Arranged and connected peripheral circuits
    [GalaxyModPCB.kicad_pcb]
2023-08-08 Neatened and connected vias
    [GalaxyModPCB.kicad_pcb]
2023-08-08 Rearranged and wired inputs
    [GalaxyModPCB.kicad_pcb, GalaxyModPCB.kicad_sch]
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2023-08-09 Removed unnecessary 3.3 net
    [GalaxyModPCB.kicad_sch]
2023-08-09 Imported changes into PCB
    [GalaxyModPCB.kicad_pcb]
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2023-08-09 Updated PCB with new annotations
    [GalaxyModPCB.kicad_pcb]
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2023-08-09 Minor tweaks to position
    [GalaxyModPCB.kicad_pcb]
2023-08-09 Fixed most violations and errors
    [GalaxyModPCB.kicad_pcb]
2023-08-09 Fixed Diode silkscreen issue
    [GalaxyModPCB.kicad_pcb]
2023-08-09 Resolved courtyard overlap
    [GalaxyModPCB.kicad_pcb]
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2023-08-09 Changed boot jumper to pad
    [GalaxyModPCB.kicad_pcb]
2023-08-09 Changed power header to proper size
    [GalaxyModPCB.kicad_pcb, GalaxyModPCB.kicad_sch]
2023-08-09 Updated USB header to pads
    [GalaxyModPCB.kicad_pcb]
2023-08-09 Replaced RGB header with 2.5mm
    [GalaxyModPCB.kicad_pcb, GalaxyModPCB.kicad_sch]
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2023-08-10 Change mosfet to bjt
    [GalaxyModPCB.kicad_sch]
2023-08-10 Imported BJTs into PCB
    [GalaxyModPCB.kicad_pcb]
2023-08-10 Major LED placement change
    [GalaxyModPCB.kicad_pcb, GalaxyModPCB.kicad_sch]
2023-08-10 Connected all but islands
    [GalaxyModPCB.kicad_pcb, GalaxyModPCB.kicad_sch]
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2023-08-10 Changed outer layer fill to solid
    [GalaxyModPCB.kicad_pcb]
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2023-08-10 Updated schematic with BJTs
    [GalaxyModPCB.kicad_sch]
2023-08-10 Replaced BJTs
    [GalaxyModPCB.kicad_pcb]
2023-08-12 Added resistor to motor
    [GalaxyModPCB.kicad_sch]
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2023-08-13 Updated resistors for motor control
    [GalaxyModPCB.kicad_sch]
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2023-08-14 added gnd to jtag connector -> routing up next
    [GalaxyModPCB.kicad_pcb, GalaxyModPCB.kicad_sch]
2023-08-14 Updated Kicad and LED
    [GalaxyModPCB.kicad_sch]
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2023-08-14 Updated footprints in schematic
    [GalaxyModPCB.kicad_sch]
2023-08-14 Flipped JTAG header
    [GalaxyModPCB.kicad_sch]
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2023-08-14 Updated LED to correct size
    [GalaxyModPCB.kicad_pcb]
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2023-08-15 Updated labels and traces
    [GalaxyModPCB.kicad_pcb, GalaxyModPCB.kicad_sch]
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2023-08-15 Created Gerber files for fabrication
    [GalaxyModPCB-B_Cu.gbl, GalaxyModPCB-B_Mask.gbs, GalaxyModPCB-B_Paste.gbp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]
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2023-08-16 Updated LED definitions
    Updated definitions to correspond with their correct LED on the board
    [main.cpp]
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2023-08-19 Fix to state change conditions
    [main.cpp]
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2023-08-22 Fixed right-angle trace connection
    [GalaxyModPCB.kicad_pcb]
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2023-08-27 Removed button emulation function
    Commented the logic that prevents the other switches from cycling states when powered off. This is a good design in the original but with a device that is always on, even when the lights are off, it doesn't feel right, especially in the web interface.
    [main.cpp]
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2023-09-08 Fixed transistor
    [GalaxyModPCB.kicad_sch]
2023-09-08 Changed back to triangle jumper
    [GalaxyModPCB.kicad_sch]
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2023-09-08 Updated PCB
    Incorporated fuze and fixed transistor footprints
    [GalaxyModPCB.kicad_pcb, GalaxyModPCB.kicad_sch]
2023-09-08 Small positioning fixes
    [GalaxyModPCB.kicad_pcb]
2023-09-08 Improved power to plane
    [GalaxyModPCB.kicad_pcb]
2023-09-09 Replaced RVP diode with PMOS
    Replaced RVP diode with PMOS fet in sketch for reduced power loss
    [GalaxyModPCB.kicad_sch]
2023-09-10 Replaced RVP Diode with PMOS
    [GalaxyModPCB.kicad_pcb]
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2023-09-11 Greatly improved part placement
    [GalaxyModPCB.kicad_pcb]
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2023-09-12 Fixed reference mismatch
    [GalaxyModPCB.kicad_pcb, GalaxyModPCB.kicad_sch]
2023-09-12 Fixed labels
    [GalaxyModPCB.kicad_pcb]
2023-09-28 Pin definition fix
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2023-09-28 Generated fabrication files for Rev 1,1
    [GalaxyModPCB-B_Cu.gbl, GalaxyModPCB-B_Mask.gbs, GalaxyModPCB-B_Paste.gbp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]
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
